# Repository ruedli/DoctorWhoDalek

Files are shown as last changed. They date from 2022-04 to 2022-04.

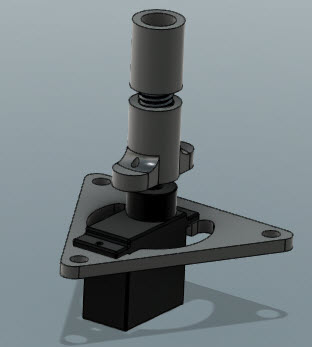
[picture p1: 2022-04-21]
DalekHardware/Dalek3DPrint/Dalek mount3.jpg

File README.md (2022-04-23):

# DoctorWhoDalek

Make a Dalek for the Williams Doctor Who pinball move, like Williams intended to... And more: animate 165 RGB LEDS.

See it move here: https://www.youtube.com/watch?v=ovQI1cAGlCM

The first series of the Williams dr Who pinball (from 1989) had a motor to move the Dalek in its topper. For budget reason this was removed after a fey models, but.... The firmware STILL supports it.

This project makes the Dalek move again, using a small servo, an ESP8266 D1 mini (Wemos) and this code. You find all information to hook it up in the "DalekHardware" directory. 



The .lm files contain the stripboard PCB's that I designed (using "Lochmaster"). For the PCB to mount the ESP on, see the ESP D1 mini .LM file.

Next I went a step further, and also added 125 RGB LEDS (25 colums of 5 LEDS) in the foot and 39 RGB leds in the head. The sketch allows you to program animations (stored in directories of the D1 mini's flash drive), played out at 100 frames per second. You can also conveniently program these animations from the Dalex.xslm (Excel) file. It uses an MQTT interface to directly send patterns from the excel into your Dalek for previewing. You can also set speed and movementtypes through MQTT and the Excel file.



Leds, Ring, Nose/eyes all can be programmed with "standby" patterns, as well as "active" patterns. The Leds in the base animate as and when the head is operated, nose/eyes and the Leds in the ring are animated when the pinball lights up the flasher light in the head (which is gone now). This flasher is pinball solenoid14. the servo is operated by the motor solenoid (solenoid25).

Here you see it interact with the test screen of the pinball machine itself and wiggle the head and animate the LEDs. In reality the LEDS look much better!
https://www.youtube.com/watch?v=p3V4AYly9XI

In essence the LEDS form 4 simple matrices, all interface with one Holtek HT16K33 led driver chip. Each led driver can operate 128 LEDS, one RGB needs 3 LEDS, so I needed 4 drivers for my 164 RGB Leds. The flashmemory of the D1 mini contains the text files that have the LED patterns to animate. It supports running text as well! The wiring of the 4 LED drivers looks intimidating, but is not complex, just a lot of wires! 

All these 164 LEDs are animated with only 4 wires using standard I2C so,: +5V, GND, SCL and SDA. So the head needs these 4 wires, as well as 3 wires for a micro servo. These go to the ESP8266 D1 mini (wemos). I also put 3 step down convertors on that board for 5V for the ESP, 6V for the servo and 5.5V for the LEDS.

The interface between pinball and ESP D1 mini has 6 wires: 12V, GND, row1 (J208-1), column8 (J206-9), solenoid25 (J122-1) and solenoid14 (J128-2).

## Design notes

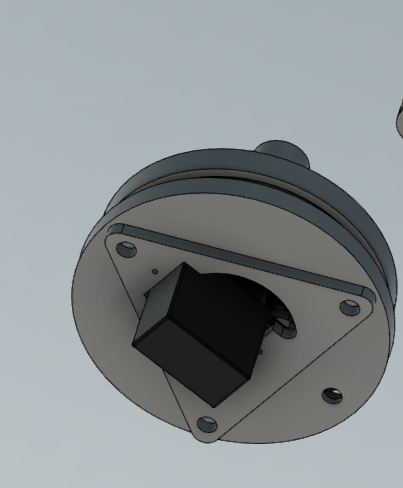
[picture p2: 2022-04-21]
DalekHardware/Dalek3DPrint/Dalek mount2.png

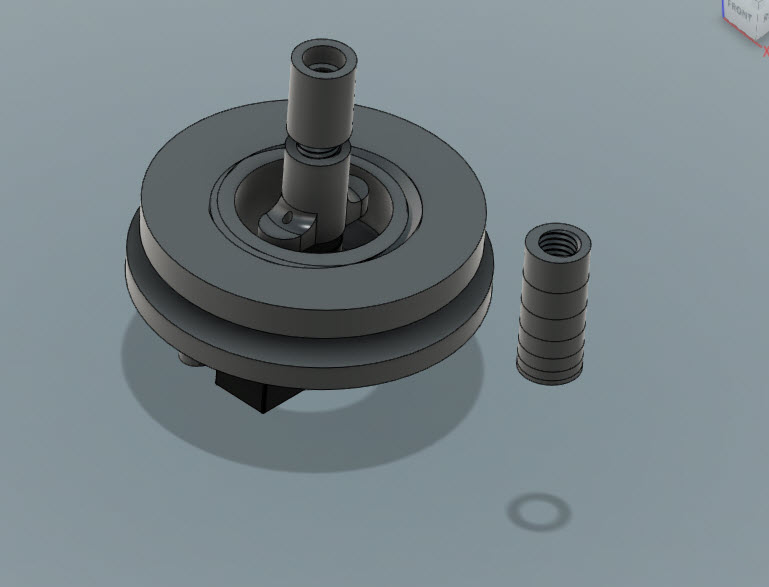
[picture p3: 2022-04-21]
DalekHardware/Dalek3DPrint/Dalek mount1.jpg

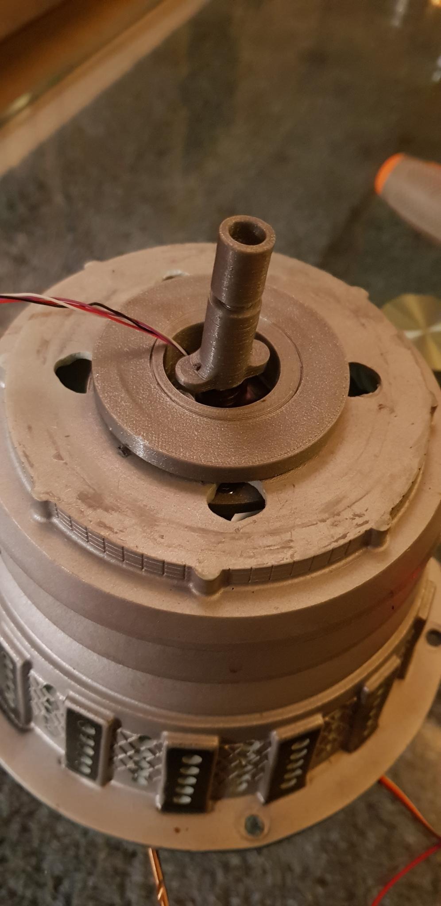
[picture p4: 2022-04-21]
DalekHardware/Dalek3DPrint/servo MG90S.jpg

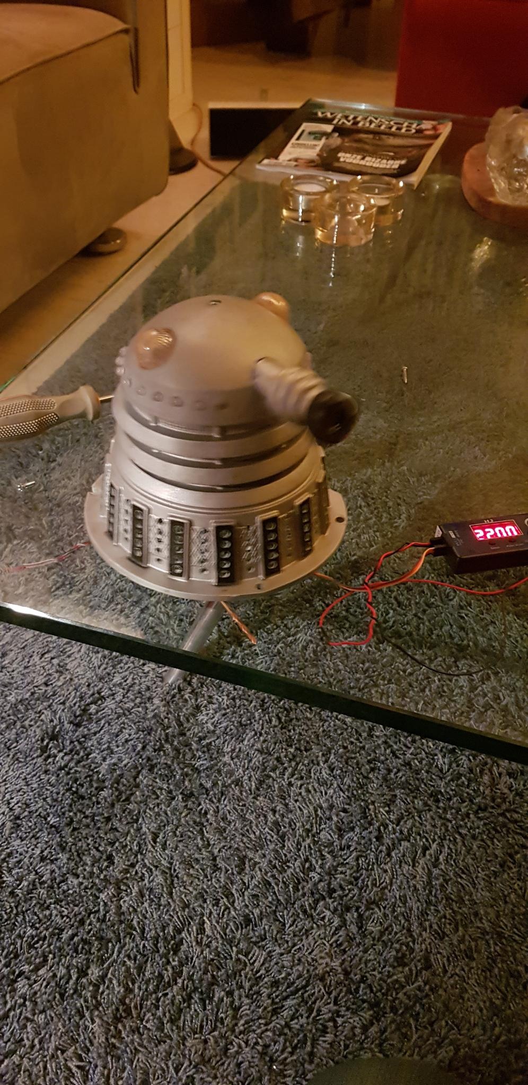
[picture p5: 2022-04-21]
DalekHardware/Dalek3DPrint/Dalek dr Who Pinball.jpg

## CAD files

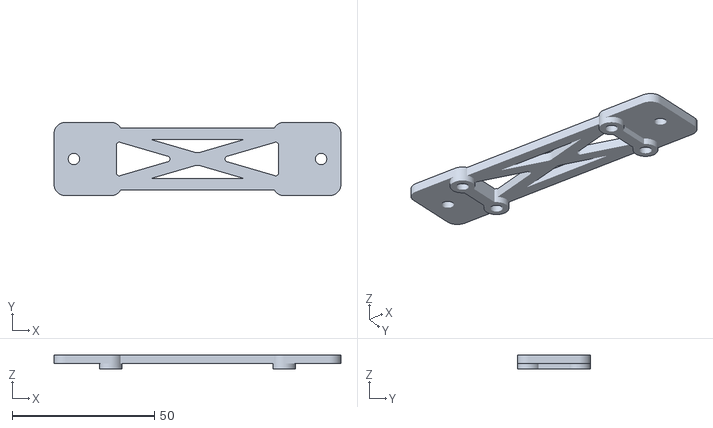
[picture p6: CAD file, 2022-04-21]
DalekHardware/Dalek3DPrint/PCBbracket.stl
101.0 x 25.8 x 5.00

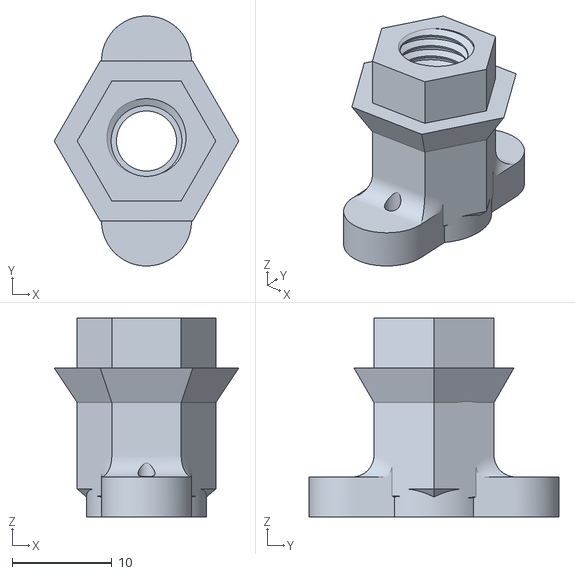
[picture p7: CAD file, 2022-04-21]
DalekHardware/Dalek3DPrint/ServoHorn.stl
18.5 x 25.0 x 19.9

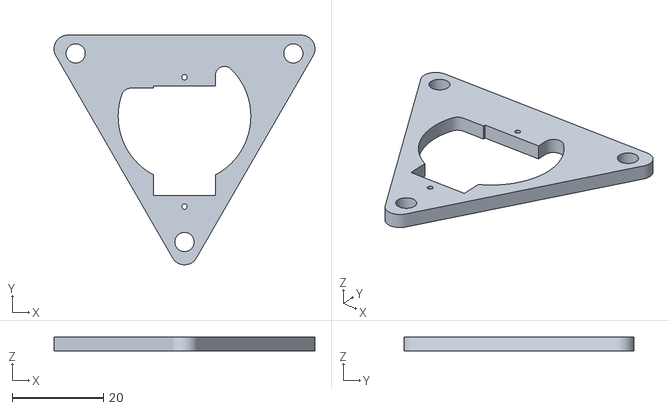
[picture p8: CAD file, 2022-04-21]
DalekHardware/Dalek3DPrint/ServoFixture.stl
57.1 x 50.2 x 3.00

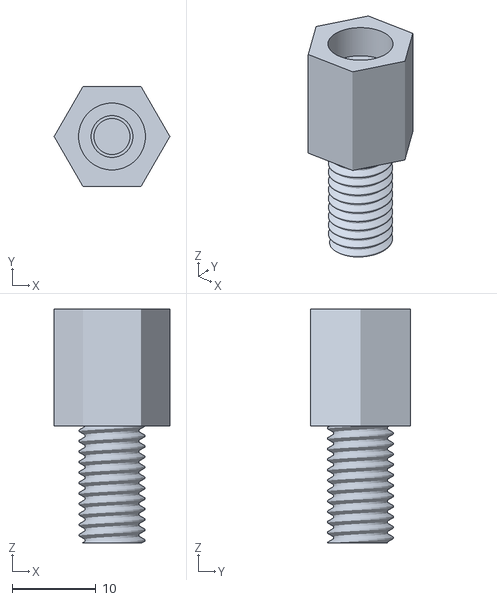
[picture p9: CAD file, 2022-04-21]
DalekHardware/Dalek3DPrint/HeadMount-14.stl
13.9 x 12.0 x 28.0

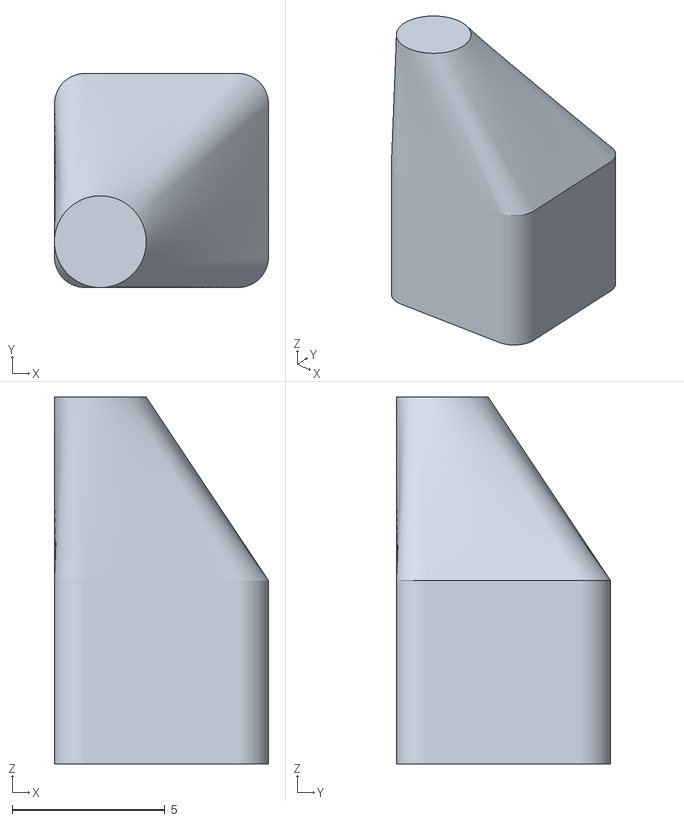
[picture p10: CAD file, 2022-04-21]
DalekHardware/Dalek3DPrint/Steun.stl
7.00 x 7.00 x 12.0

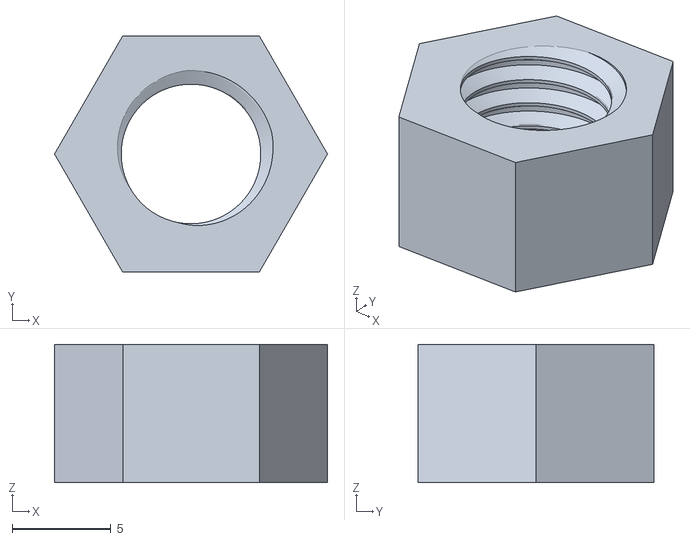
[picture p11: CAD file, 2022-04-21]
DalekHardware/Dalek3DPrint/Nut7.stl
13.9 x 12.0 x 7.01

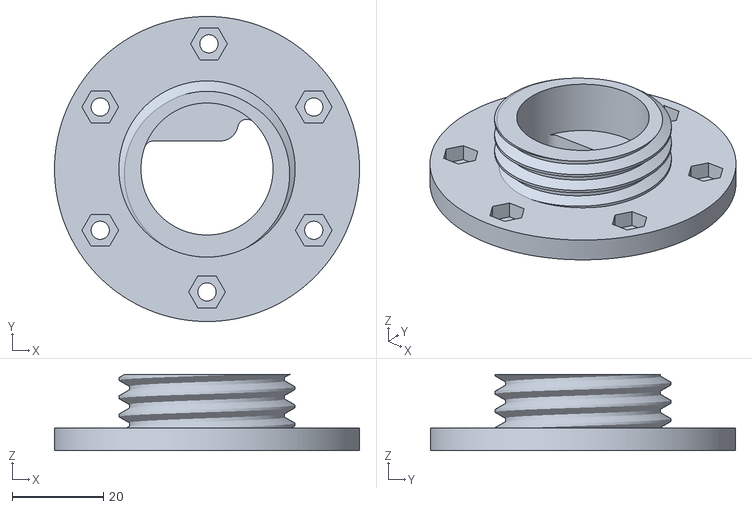
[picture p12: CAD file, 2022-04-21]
DalekHardware/Dalek3DPrint/BottomFitting.stl
67.0 x 67.0 x 16.7

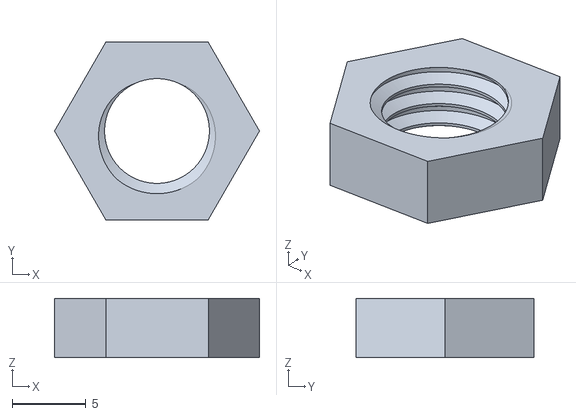
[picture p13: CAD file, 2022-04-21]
DalekHardware/Dalek3DPrint/Nut4.stl
13.9 x 12.0 x 4.00

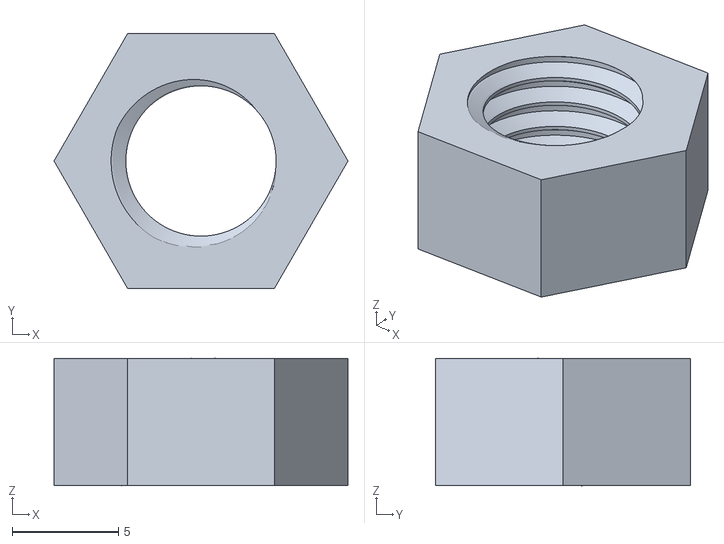
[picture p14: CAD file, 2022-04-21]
DalekHardware/Dalek3DPrint/Nut6.stl
13.9 x 12.0 x 6.01

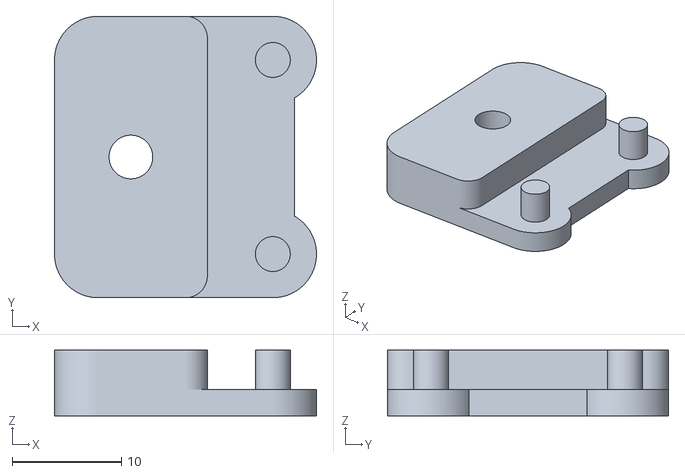
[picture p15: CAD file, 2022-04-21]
DalekHardware/Dalek3DPrint/PCBpart_2X.stl
24.0 x 25.8 x 6.00

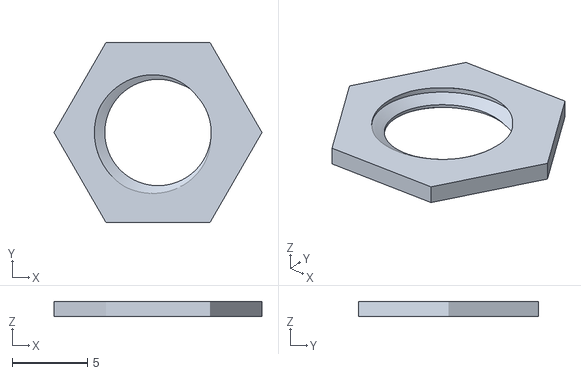
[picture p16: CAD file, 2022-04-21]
DalekHardware/Dalek3DPrint/Nut1.stl
13.9 x 12.0 x 1.01

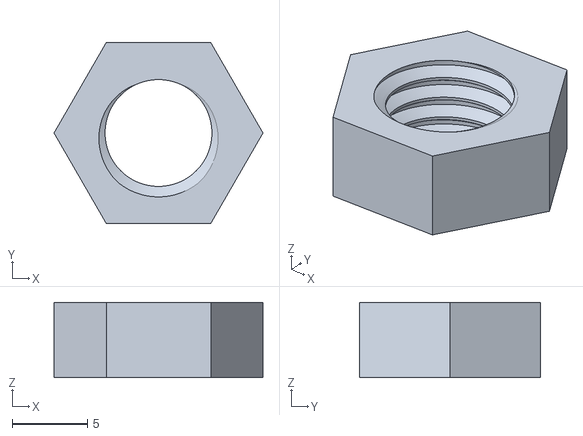
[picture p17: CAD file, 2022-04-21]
DalekHardware/Dalek3DPrint/Nut5.stl
13.9 x 12.0 x 5.00

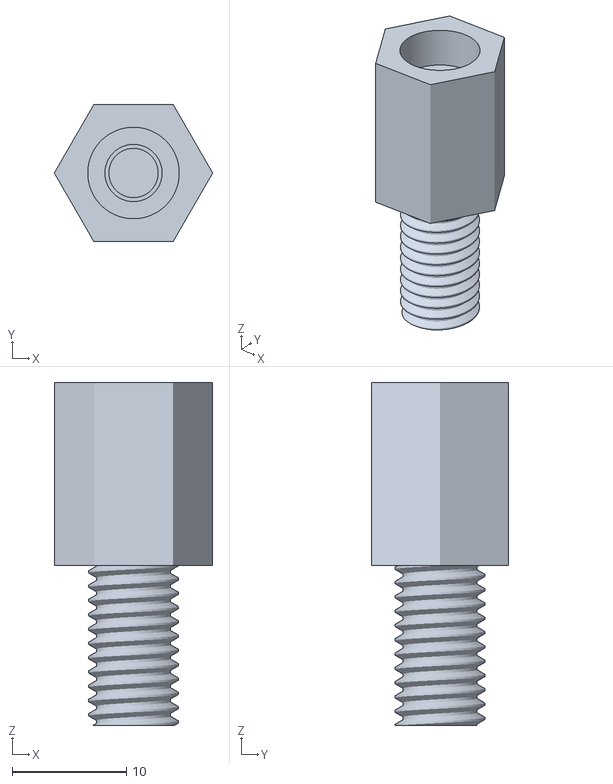
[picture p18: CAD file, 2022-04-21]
DalekHardware/Dalek3DPrint/HeadMount-16.stl
13.9 x 12.0 x 30.0

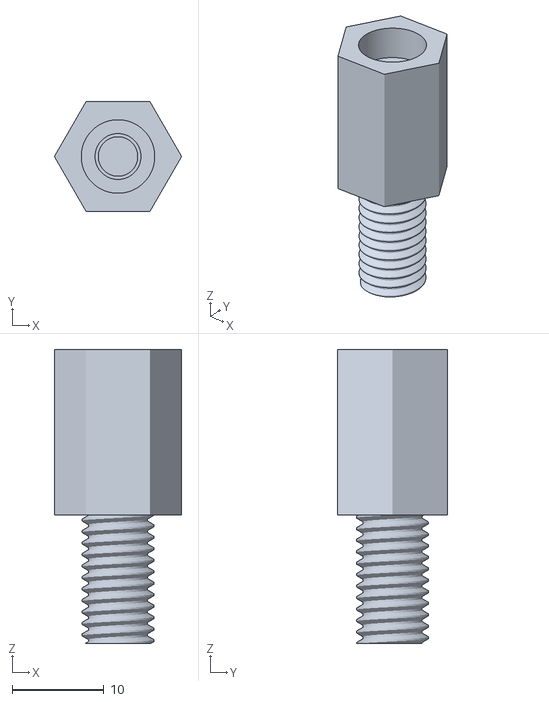
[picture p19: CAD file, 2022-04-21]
DalekHardware/Dalek3DPrint/HeadMount-18.stl
13.9 x 12.0 x 32.0

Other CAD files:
DalekHardware/Dalek3DPrint/TopperFitting.stl
DalekHardware/Dalek3DPrint/Nut2.stl
DalekHardware/Dalek3DPrint/Nut3.stl
DalekHardware/Dalek3DPrint/LockingNut.stl

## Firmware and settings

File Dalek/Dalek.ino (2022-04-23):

// Set platform
#define ESP8286
//#define Arduino

#include <ESP8266WiFi.h>
#include <WiFiClient.h>

// include MDNS (for WiFimanager)
#ifdef ESP8286
#include <ESP8266mDNS.h>
#endif

//Not needed! although the OTA example sketch contained them
#ifndef platformio_build
#include <WiFiUdp.h>
#endif

// Set these defines to match your environment, copy initial file from OctoPlugout.config.h.RELEASE ========
#include "DalekConfig.h"

#ifdef ESP8286
#include <WiFiManager.h> // https://github.com/tzapu/WiFiManager
#include <ArduinoOTA.h>

// Includes for MQTT
#include <PubSubClient.h>
#endif

#include <Metro.h>
#include <Wire.h>  // Comes with Arduino IDE, used for driving the LCD using 
//#include <LiquidCrystal_I2C.h>
//#include <SoftwareSerial.h>

#ifdef Arduino
#include <EEPROM.h>
#elif defined ESP8286
#include <EEPROM.h>
#endif

#include <Servo.h>

#ifdef __TM1640
#include <TM1638.h> // required because the way arduino deals with libraries
#include <TM1640.h>
#endif

#ifdef __HT16K33
// include the wire libray for i2c
#include <Wire.h>  // Comes with Arduino IDE
// include my driver library:
#include <DalekDriver.h>    // A library for managing a driver for 128 LEDS; 
							// it supports a configuration of 8 columns with 5 RGB LEDS in them. (so 8x5x3=120 LEDS)
							// The remaining 8 LEDS can also be set. 
#endif

#define NOCATCH_UP
#include <Metro.h>

#ifdef Arduino
// SPI library for SD card, + SD card library
#include <SPI.h>
#include <SD.h>
//Define the used pins:
/*
 The circuit for the SD card reader:
  * SD card attached to SPI bus as follows:
 ** MOSI - pin 11 on Arduino Uno/Duemilanove/Diecimila
 ** MISO - pin 12 on Arduino Uno/Duemilanove/Diecimila
 ** CLK  - pin 13 on Arduino Uno/Duemilanove/Diecimila
 ** CS   - depends on your SD card shield or module, it is pin 10 in this scetch
*/
#define __chipSelect 10
#endif
#ifdef ESP8266
//improves read speed for LittleFS
#define CONFIG_LITTLEFS_CACHE_SIZE 512	

#include <FS.h>
#include <LittleFS.h>
#endif


#ifdef __TM1640
#define __Clock_1 4
#define __Data__1 5
#define __Clock_2 6
#define __Data__2 7
#define __Clock_3 8
#define __Data__3 9
// Each TM1640 is connected using a distinct Data and a clock pin:
LedDriver module1(__Data__1, __Clock_1);
LedDriver module2(__Data__2, __Clock_2);	
LedDriver module3(__Data__3, __Clock_3);
#endif 

#ifdef __HT16K33
// Leftmost LEDS
#define __DriverAddress1 0x70
// Center LEDS 
#define __DriverAddress2 0x71 
// Righthand LEDS 
#define __DriverAddress3 0x72
// 15 LEDS for nose(5RGB), eyes(2x5RGB) and a ring with 24 RGB LEDS on the head. 
#define __DriverAddress4 0x73

DalekDriver DisplayDrivers[3] = { DalekDriver(__DriverAddress1), DalekDriver(__DriverAddress2), DalekDriver(__DriverAddress3)};
DalekDriver HeadDriver(__DriverAddress4);

#endif 

//Loop timing using metro for the head.
Metro _BLINKprocessing = Metro(10000);	//Used for blinking the head LEDS
Metro _FLASHprocessing = Metro(10000);	//Used for flashing the head LEDS
Metro _STROBEprocessing = Metro(10000); //Used for strobing the head LEDS 

boolean EscHit = false;

boolean HighResMode = false;

//Normalmode display on lowres LEDS
#define __NormalMode 0 
//Display compressed, show left: 12 blanks right
#define __LeftMode 1 
//Display compressed, show centered: 6 blanks left and right
#define __CenterMode 2 
//Display compressed, show right: 12 blanks left
#define __RightMode 3 
int ModeDisplay = __NormalMode;

struct TimingType {
    unsigned long PatternTime[2];
	byte pointerFile[2];
	byte numberFiles[2];
    unsigned long Sol14ExtendTime;
    unsigned long Sol25ExtendTime;
	uint8_t AnimationIntensity;
	uint8_t MinIntensity;
	uint8_t MaxIntensity;
	Metro ActiveProcessing;
	Metro TimeProcessing;
	File dataFile;
	boolean HasFiles[2];
	boolean StreamIsActive;
	boolean GetNextPattern;
	boolean PatternOK;
	byte StreamSource;
	boolean WeJustBecameActive;
	boolean HowLongToRemainActive;
	boolean SwapActiveSleeping;
	const char *initS[2];
};

	// For the bug that with "short times", the second loop (activeprocessing check) is fired, just after activating.
	// To fix that we slightly delay processing till later:
	//
	// Integrated in TimingType
	//static boolean WeJustBecameActive[3] = {false, false, false};
	//static boolean HowLongToRemainActive[3] ={0,0,0}; //To be filled in when getting active.


// These properties are only relevant for the Head, so they are not contained in the TimingType structure
unsigned HP_BlinkTime[2] = {500, 500};
unsigned HP_FlashTime[2] = {200, 200};
unsigned HP_StrobeTime[2] = {100, 100};

boolean Blink_on=false;
boolean Strobe_on=false;
boolean Flash_on=false;

#define N_L_eye 1
#define N_R_eye 2
#define N_Nose  3

// Animation parameters and constants
#define __No  			0
#define __Yes 			1
#define __Continuous    2
#define __OFF 			3
#define __ON  			4
#define __BLINK		    8
#define __FLASH		   12
#define __STROBE	   20
#define __STROBEBLINK  24
#define __STROBEFLASH  28
#define __ApplySTROBE  (__STROBE - __ON)

#define __stream_LED 0
#define __stream_HEAD 1
#define __stream_RING 2

#define __stream_Active 0
#define __stream_Sleeping 1

#define __streamFrom_SD 0
#define __streamFrom_MQTT_SD 1
#define __streamFrom_MQTT_Wait 2
#define __streamFrom_MQTT_Loop 3
#define __streamFrom_Serial 4

//Headanimation, stringbased
TimingType HP_TimeTiming[3]  = {{	.Sol14ExtendTime = 0, 
									.Sol25ExtendTime = 5000,
									.AnimationIntensity = 7,
									.MinIntensity = 0,
									.MaxIntensity = 7,
									.StreamIsActive = false,
									.GetNextPattern = false,									
									.PatternOK = false,
									.StreamSource = __streamFrom_SD,
									.WeJustBecameActive = false,
									.HowLongToRemainActive = 0,
									.SwapActiveSleeping = false,
									.initS = {"Y 0,0,0,0,0,0,0,0,0,0,0,0,0,0,0,0,0,1,0,0,130,0,0,68,0,0,40,0,0,16,0,0,1Z", "Y 0Z"}},
								{	.Sol14ExtendTime = 5,
									.Sol25ExtendTime = 0,
									.AnimationIntensity = 7,
									.MinIntensity = 0,
									.MaxIntensity = 7,
									.StreamIsActive = false,
									.GetNextPattern = false,									
									.PatternOK = false,
									.StreamSource = __streamFrom_SD,
									.WeJustBecameActive = false,
									.HowLongToRemainActive = 0,
									.SwapActiveSleeping = false,
									.initS = {"C444", "C000"}},
								{	.Sol14ExtendTime = 5,
									.Sol25ExtendTime = 0,
									.AnimationIntensity = 7,
									.MinIntensity = 0,
									.MaxIntensity = 7,
									.StreamIsActive = false,
									.GetNextPattern = false,									
									.PatternOK = false,
									.StreamSource = __streamFrom_SD,
									.WeJustBecameActive = false,
									.HowLongToRemainActive = 0,
									.SwapActiveSleeping = false,
									.initS = {"A00000000004Z", "A0Z"}}
								};
														
#define __update_display_needed 2 // bit 1: bit 0 indicates the stream: active (0) -or- sleeping (1)
#define __update_display_not_needed 0

boolean ForceOut = false;   // escape out when entering redirection of the SD stream to serial...
//byte ShowSerialInput = __stream_NoStream; // determine whether to loop, or to show a fixed pattern as typed in...

byte L_eye = 4;
byte R_eye = 4;
byte Nose = 4;

byte R_eye_pattern[2] = {__ON,__ON};
byte L_eye_pattern[2] = {__ON,__ON};
byte Nose_pattern[2] = {__ON,__ON};

byte R_eye_nextcol[2] = {1,1};
byte L_eye_nextcol[2] = {1,1};
byte Nose_nextcol[2] = {1,1};

boolean ShowFilenames=false;	  // This shows the filenames on serial log. use command A -> T to toggle.

////////////////////////////////////

#define __RR_PROJECT 10      // project stored in EEPROM(100), so that parameters are not read from another project.
#define __RR_VERSION 4       // version for this project that the parameters can be interpreted for, to avoid incompatibilities.
#define __RR_SW_Version "4.0"// The software (WIP)

#define __ShapeSine 0
#define __ShapeSaw 1
#define __ShapeBlock1 2
#define __ShapeBlock2 3
#define __ShapeRandom 4

#define __MoveByPinball 0   			// Who (listening to the Solenoid25 signal
#define __MoveAutonomous 1  			// Sweeping moving all by itself continuously
#define __MoveFixedLeft 2				// Fixed in left position (adjustable)
#define __MoveFixedCenter 3 			// Fixed in center position (adjustable)
#define __MoveFixedRight 4				// Fixed in right position (adjustable)
#define __MoveByPinball_stop_nocenter 5 // Who (listening to the Solenoid25 signal, stop immedieately when solenois signal disappears
#define __MoveByPinball_stop_center 6	// Who (listening to the Solenoid25 signal, stop immedieately when solenois signal disappears, center slowly

#define __DelayTimeForCentering 60000

//#define DEBUG
#ifdef DEBUG
#define DEBUG_OUT(a,b) Serial.print(a); Serial.print(F(":\t")); Serial.println(b);
#else
#define DEBUG_OUT(a,b) // a b
#endif

/* Doctor WHO, moving Dalek
 by Ruud Rademaker
 
 The first 10 Bally Doctor WHO Pinball machines (prototypes) had a moving Dalek on the top of
 the cabinet which was removed lateron for production cost reasons.
 
 Solutions exist to implement a moving Dalek, using relatively expensive motors and a gear (for left-right-left movement)
 together with an opto switch to detect the mid position.
 
 This project realizes a cheap and easy to install Arduino based solution, accomplished from:
 
 Further, since version 3
 - The TM1638/TM1640 is now obsolete, instead an LCD display is used
 - As input options there are now:
   o A 5 button keyboard, basical up/down left/right and enter.
   o a rotary switch (software in place, hardware is bouncing too much... for now it is disabled.
  
 INPUTS
 - PIN   6: the solenoid drive #25 - to know whether movement is desired during gameplay.
 - PIN   x: the solenoid drive #14 - to know when to flash the LEDS in the head (new in v 4.0)
 - PIN  A0: 5 buttons keyboard, with resistors to distinct 5 keys using one analog input. This uses the arrangement as off the robo LCD shield
 - PIN 7 : Rotary switch button
 - PIN 8 : Rotary switch A
 - PIN 9 : Rotary switch B
 
 OUTPUTS
 - PIN 5 opto switch output for Switch 81 in order to signal the mid position
  (The pinball machine detects that the Dalek is present and in the middle in this way).
 - PIN 4 A servo signal to sweep the head
 
 PARAMETERS
 All parameters are saved to EEPROM upon command.
 The device can be controlled and programmed using the Serial IO.

As of version 4.0, what used to be in two separate arduino's is now combined in one ESP32 D1 mini:

Animated RGB Leds: Designed for the DALEK of a dr WHO pinball 
This sketch supports animation of RBG LEDS using TM1640 modules.

One TM1640 or HT16K33 chip can drive 128 LEDS
This implies: maximum of 42 RGB leds (126 of the 128) and still 2 LEDS "left" 
              -or- (like I use them) 40 RGB LEDS (120 of the 128) and 8 LEDS left. 
			  
A TM1640  driver uses COMMON   ANODE LEDS for column 1-24 and common CATHODE for column 25
A HT16K33 driver uses COMMON CATHODE LEDS for column 1-24 and common   ANODE for column 25

The LEDS can either be driven in a LOWRES mode: using only 2 drivers
Driver 1: 8x5 = 40 RGB LEDS
Driver 2: 5x5 = 25 RGB LEDS

Alternatively, HIHGRES mode you can hook up 3 driver chips and control:
TM1640 1: (Column  1- 8) 8x5 = 40 RGB LEDS (120 of the 128)
TM1640 2: (Column  9-16) 8x5 = 40 RGB LEDS (120 of the 128)
TM1640 3: (Column 17-24) 8x5 = 40 RGB LEDS (120 of the 128)

Highres is easier to solder, as the LEDS are closer together, and the wires can easily be soldered together.
I do recommend however putting the LEDS on PCB's: per driver one board with 2 rows 
(interfacing to the driver and other boards), and tow PCB's with 3 rows each. This makes 8 rows in total.
I based it on stripboard that connects all the non-common wires of the LEDS. 
The common wires are soldered mid-air, above the board: 5 common wires of the 5 RGB LEDS in each column,
giving you a matrix of EACH driver (there are 3 in total) with 8x15 LEDs, so 8x5 RGB leds.  

The remaining 3 times 8 LEDS = 24 LEDS are used as follows:
Column 25: 1x5 = 5 RGB LEDS, uses therefore 15 of the remaining 24 LEDS of the three drivers.
This column 25 is built using 
- COMMON CATHODE for the TM1640 -or-
- COMMON   ANODE for the HT16K33

The LAST 9 remaining LEDS are will be used (together with optocouplers to couple leds
    from different drivers to one common cathode LED) for a RGB LEDs in the 
- NOSE, 
- RIGHT EYE
- LEFT EYE

-or-

- A 4th driver HT16K33 totally dedicated to the HEAD leds

See DalekDriver.cpp for layout of the LEDS over the buffers.

All rights reserved,
have fun 

Ruud Rademaker

firstname.lastname(at)gmail.com

The animations are stored in text files on an SD card, or in the LittleFS file system.
Text files must be like: SEQnnnn.TXT where n is a digit [0-9]. So: SEQ0000.TXT, SEQ0001.TXT, SEQ0002.TXT etc...
Version 4.0 uses 6 directories (ending in H or R: while the head is not moving (H for holding) or when the head is moving (R for Running)) to store files:

LedH and LedR: for the 125 Dalek body RGB leds
HeadH and HeadR: for the 3x5 nose, left eye and right eye LEDS.
RingH and RingR: for the 24 RGB leds in the head (ring shaped).

There are two modes in which these are animated:
- Animation
- SingleCommand

In animation mode, files are read from SD / LittleFS files, or 
when no files are available an in program default per stream is used.

In singleCommand mode, the LEDS follow the command provided over serial or MQTT.

When in animation mode, enter ESC or @ then the mode you want to be providing commands for:
L for leds in the base
H for the eyes/nose (left/nose/right)
R for the ring of leds in the head
A resume animation mode.

-or- provide an MQTT topic with the message (see MQTT overview of topics/commands)

When in SingleCommand mode, hit ESC or @ to obtain the selection menu, from which you can enter 
another SingleCommand mode, or resume animation,

-or- provide MQTT topic "animate" with optional message to play a file.

The following commands are supported in textfiles AND on the USB input.
I used putty with serial and/or a Bluetooth card attached to the pro for this purpose, 
so you can play with it from your PC (for both arduino as D1 mini), or MQTT for the ESP32 D1 mini.

All patterns for the base and the ring set the LEDS to a specified color.
For the eyes/nose blinking/flashing/strobing patterns can be set.

This works as follows:
The pattern time determines how long the pattern is displayed. During this LEDS can blink / flash / strobe.

With blink time you specify its on and off time. Blink=500 means 0.5s on and 0.5 seconds off.
When you specify flashtime=0, these (blink) times apply.
When flashtime>0, the leds will be on only for the flash. So:
blink=500, flash = 50 means: 0.05s on, and 0.095s off.
blink=500, flash = 950 means: 0.95s on, and 0.05s off.
blink=500, flash = 500 means: 0.5s on, and 0.5s off. This is the same as blinking.
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
void loop() 
{
	static float x=0;             	// Where we are relative to the interval ([0, 1])
	static int   Spos=1500;       	// variable to store the servo position
#ifdef DEBUG
	static int   Opos=1500;       	// variable to store the servo position
	static int   OOpos=1500;       	// variable to store the servo position
	static int   Count=0;       	// variable to store the servo position
#endif
	static byte  ProcessingPhase=0;	// In order not to do EVERYTHING at once in the loops: each loop does "one task" in sequence.
	static int  LastKeyPressed=0;   // Used for de-bouncing the keys...
	boolean Solenoid25;		// Used for capturing the hardware pin status, it is FALSE when the solenoid is activated.
	boolean Solenoid14;		// Used for capturing the hardware pin status, it is FALSE when the solenoid is activated.
	static boolean OldSolenoid25 = false;
	static boolean OldSolenoid14 = false;
	static unsigned long LoopTime = millis();
	static boolean MeasureLoop = false;
	
	static unsigned long _TimeRandomShape;   // Here we detect whether it is time to select a new movement mode...
	static unsigned long _TimeLastMovement;	 // Detecting whether it is time to move to the center pos
	static boolean _NeedToCenter = false;	 // Ensures that after a minut we fully return to the center.				
	
	unsigned long Now = millis();
	
	#ifdef ESP8286
	MDNS.update();
	
	doWiFiManager();

	ArduinoOTA.handle();	
	#ifdef def_mqtt_server
	bool mqtt_connected = false;
	
	if (mqtt_active) {
		if (MQTTclient.connected()) {
			mqtt_connected = true;
		} else {
			#ifdef DEBUG
			Serial.println(F("Attempt to reconnect MQTTn in loop"));
			#endif
			mqtt_connected = reconnect_mqtt();
		}

		if (mqtt_connected) {
			if (!MQTTclient.loop()) {
				#ifdef DEBUG
				Serial.print(F("Calling MQTT Loop FAILED"));
				#endif
			}
		}
		
		#ifdef DEBUG
		if (mqtt_connected != mqtt_last_connected) {
			if (mqtt_connected) {
				Serial.println(F("In loop: mqtt is CONNECTED"));
			} else {
				Serial.print(F("In loop: mqtt is DISCONNECTED"));
			}
			mqtt_last_connected = mqtt_connected;
		}
		#endif
		
		if (ReportNfiles) {
			sprintf(msg,"%d active and %d sleeping LED streams found", HP_TimeTiming[__stream_LED].numberFiles[__stream_Active], HP_TimeTiming[__stream_LED].numberFiles[__stream_Sleeping]);
			PublishMQTT(def_mqtt_topic, "/NledStr", msg);

			sprintf(msg,"%d active and %d sleeping HEAD streams found", HP_TimeTiming[__stream_HEAD].numberFiles[__stream_Active], HP_TimeTiming[__stream_HEAD].numberFiles[__stream_Sleeping]);
			PublishMQTT(def_mqtt_topic, "/NheadStr", msg);

			sprintf(msg,"%d active and %d sleeping RING streams found", HP_TimeTiming[__stream_RING].numberFiles[__stream_Active], HP_TimeTiming[__stream_RING].numberFiles[__stream_Sleeping]);
			PublishMQTT(def_mqtt_topic, "/NringStr", msg);
			
			ReportNfiles = false;
		}
	}
	#endif

	#endif

	Solenoid25 = (digitalRead(_Solenoid25Pin) == LOW);
	Solenoid14 = (digitalRead(_Solenoid14Pin) == HIGH);
	
	#ifdef DEBUG
	if (Solenoid25!=OldSolenoid25) {
		DEBUG_OUT("Solenoid 25", Solenoid25 ? "pressed" : "released");
		OldSolenoid25=Solenoid25;
	}
	if (Solenoid14!=OldSolenoid14) {
		DEBUG_OUT("Solenoid 14", Solenoid14 ? "released": "pressed");
		OldSolenoid14=Solenoid14;
	}
	#endif
	
	if (_ServoLoop.check() == 1) {
		// Move the servo
		if (_InvertedServo) {
			_Servo.writeMicroseconds(3000 - Spos);
		} else {
			_Servo.writeMicroseconds(Spos);
		}

		// Handle all buttons

		// Calculate where we are with respect to the wave form on a scale of (0 to 1)

		//if (( (digitalRead(_Solenoid25Pin) == HIGH) && !((module.getButtons() & B10000000) == B10000000)) && _WeAreCENTERED && (_MovementMode == 0)) {
		// when Solenoid25 is true, we should move, 
		// when solenoid25 is false: DO NOT MOVE
		if (_MovementMode == __MoveFixedLeft) {
			x = 0.25;
			Spos = _Left;
		} else if (_MovementMode == __MoveFixedCenter) {
			x = 0.5;
			Spos = _Center;
		} else if (_MovementMode == __MoveFixedRight) {
			x = 0.75;
			Spos = _Right;			
		} else if (!Solenoid25 && (_MovementMode != __MoveAutonomous)) {
			// Here we should STOP moving, but under some exceptions it will move BACK to the center
			//
			// NOTE the actual Dr Who pinball machine firmware activates the solenoid signal to trigger 
			// movement towards the center, when stopped and not centered!
			if ( (_MovementMode == __MoveByPinball_stop_center) && !_NeedToCenter ) {
				// Do nothing, but move to the center after a minute.
				if ((millis() - _TimeLastMovement) > __DelayTimeForCentering) {
					_NeedToCenter = true;
				}
			} else if ((_MovementMode == __MoveByPinball) || _NeedToCenter) {
				// Here we just center....
				if (_WeAreCENTERED) {
					// Here we should STOP moving, but move BACK to the center, because we are close to the center
					if (_WeAreGoingRight) {
					// Target moving towards x = 0;
						if (x < 0.5) {
						  x = max(0.0, x - _Step);
						} else { 
						x = min(1.0, x +_Step);
						}
					} else {
						// Target moving towards x=0.5;
						if (x < 0.5) {
							x = min(0.5, x + _Step);
						} else {
							x = max(0.5 , x - _Step);
						}
					}
				} else {
					// OR Continue moving the normal way towards the center...
					x += _Step;
					// Make sure we stay in the [0;1] interval.
					x = MyMap(x, 1.0);			
					// Calculate Servo position for the next time			
				}
				// We moved towards the center... BACK or forward, once centered it stops
				Spos = CalcPos(x);
			}
		} else {										// Need to move
			x += _Step;
			// Make sure we stay in the [0;1] interval.
			x = MyMap(x, 1.0);			
			
			// Calculate Servo position for the next time
			Spos = CalcPos(x);
			_NeedToCenter = false;
			_TimeLastMovement = millis();
		} // end if ((digitalRead

		_WeAreRight = (x > _XMarge) && (x < 0.5 - _XMarge);
		_WeAreLeft = (x > 0.5 + _XMarge) && (x < 1 - _XMarge);
		_WeAreCENTERED = (!_WeAreRight) && (!_WeAreLeft);
		_WeAreGoingRight = (MyMap(x+0.25, 1.0) < 0.5);

		// Display the "Centered" LED.
		if (_WeAreCENTERED) {
			digitalWrite(_CenterLEDPin, LOW);
			if (_WeAreGoingRight) {
				if (MeasureLoop) {
					MeasureLoop = false;
					unsigned long Tlong = Now - LoopTime;
					LoopTime = Now;
					if (_FirstLoop) {
						_FirstLoop = false;
					} else {
						sprintf(msg, "T %.2f s, RPM %.1f", double(Tlong) / 1000.0, 60000.0 / double(Tlong));
						PublishMQTT(def_mqtt_topic, topic_Cycle, msg);
					}
				}
			} else {
				MeasureLoop = true;
			}
		} else {
			digitalWrite(_CenterLEDPin, HIGH);
		}

#ifdef noDEBUGfornow		
		if (Spos != OOpos) {
			Count +=1;
			Serial.print(_Time);
			Serial.print(" ");
			Serial.print(_Step);
			Serial.print(" ");
			Serial.print(Count);
			Serial.print(" ");
			Serial.println(x);
			OOpos = Opos;
			Opos = Spos;
		} else {
			Count=0;
		}
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

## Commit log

2022-04-22 Added HT16K33 command generation to the Dalek.xlsm
    [Dalek.xlsm]
2022-04-22 Remove unnecessary PCB files with TM1640 and Arduino Pro / Nona. Not supported anymore.
    Need to build with ESP D1 mini (Wemos) and 3 to 4 Holtek HT16K33 led drivers
    [led OPTO RESISTORS.xls]
2022-07-01 sync XLM
    [Dalek.xlsm]
2022-07-05 Just to be sure
    [Dalek.xlsm]
2022-07-06 Allow for standard order of rows of the LEDs.
    In the default config, the top row is skipped and driven by the pins for the LAST row of LEDS.
    Choose the "normal" order of LEDS, how the rows go over the Dalek.
    If REGULAR_LEDS is NOT defined, the top row is skipped and becomes the last
    so order for A0->A14 is: (BGR row 2) (BGR row 3) (BGR row 4) (BGR row 5) (BGR row 1)
2022-07-07 Made the library configuring for different soldering options.
    Fixed a rear problem in the Excel: last row was not displaying correct blue and green LEDS.
    [Dalek.xlsm]
